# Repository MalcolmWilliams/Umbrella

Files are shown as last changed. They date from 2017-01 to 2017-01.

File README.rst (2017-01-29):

========
Umbrella
========

ESP8266 based smart umbrella for art show

Hardware
========

Prototyping is done on the `Adafruit HUZZAH ESP8266 Breakout <https://www.adafruit.com/product/2471>`_
The adafruit documentation is available here: https://learn.adafruit.com/adafruit-huzzah-esp8266-breakout/overview

Software
========

The program is written in Arduino with the help of platformio. 

Code written in microPython and Lua were also tested, but deemed to be less advantageous.

Uploading Code
**************

The board needs to be put in bootloader mode and then can be uploaded in a similar fashion to other arduino boards.
To put the board into bootloader mode:

1. Hold down reset button
2. Reset the board

To upload code, the script ``upload.sh`` can be run. Or the command ``platformio run -t upload`` can be run. 

PCB
===

The design was done in Altium 16. The project is located in ``./PCB/Smart_Umbrella_Altium/Smart_Umbrella/``.
Several of the board features include: LiPo battery charging, LED's, automatic bootloader mode, battery level sensing and IO breakouts.

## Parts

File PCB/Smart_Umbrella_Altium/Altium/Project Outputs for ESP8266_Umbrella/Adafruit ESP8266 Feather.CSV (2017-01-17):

Bill of Material for
On 1/17/2017 at 11:16:41 AM
Comment | Pattern | Quantity | Components
0.1µF | 0805 | 1 | C4
1µF | 0603 | 3 | C2, C3, C5
10µF | 0805 | 1 | C1
2.2nF | 0603 | 1 | C6
22µF | 0805 | 3 | C8, C9, C11
4.7µF | 0805 | 2 | C7, C10
6.8µH | L0603 | 1 | L1
CN3065 | DFN8G-0.5-3X3MM | 1 | U2
DHT-4235A | KMR2 | 1 | SW2
ESP-12 | ESP-12 | 1 | X1
ETA1036-50S2F | SOT-23-5 | 1 | 1
Green | LED-0603 | 1 | D8
Header 10 | HDR1X10 | 2 | P1, P2 | Header, 10-Pin
Header 6 | HDR1X6 | 1 | P3 | Header, 6-Pin
JSTPH | JST-2-SMD | 1 | J1
LED | LED_5MM | 3 | D5, D6, D7
MK-12C02 | SW7-SMD-L6.7X2.7X3.2MM | 1 | SW1
MMBT3904L | SOT23-3 | 2 | Q1, Q2 | Transistor NPNBJT configuration in SOT23 package. MMBT2222 is the common NPN we use. Double check BCE configuration again layout.
Orange | LED-0603 | 1 | D9
Red | LED-0603 | 1 | D4
Res3 | J1-0603 | 17 | R1, R2, R3, R4, R5, R6, R7, R8, R9, R10, R11, R12, R13, R14, R15, R16, R17 | Resistor
WS2812B5050 | WS2812B | 3 | D1, D2, D3
XC6204B332MR | SOT-23-5 | 1 | U1

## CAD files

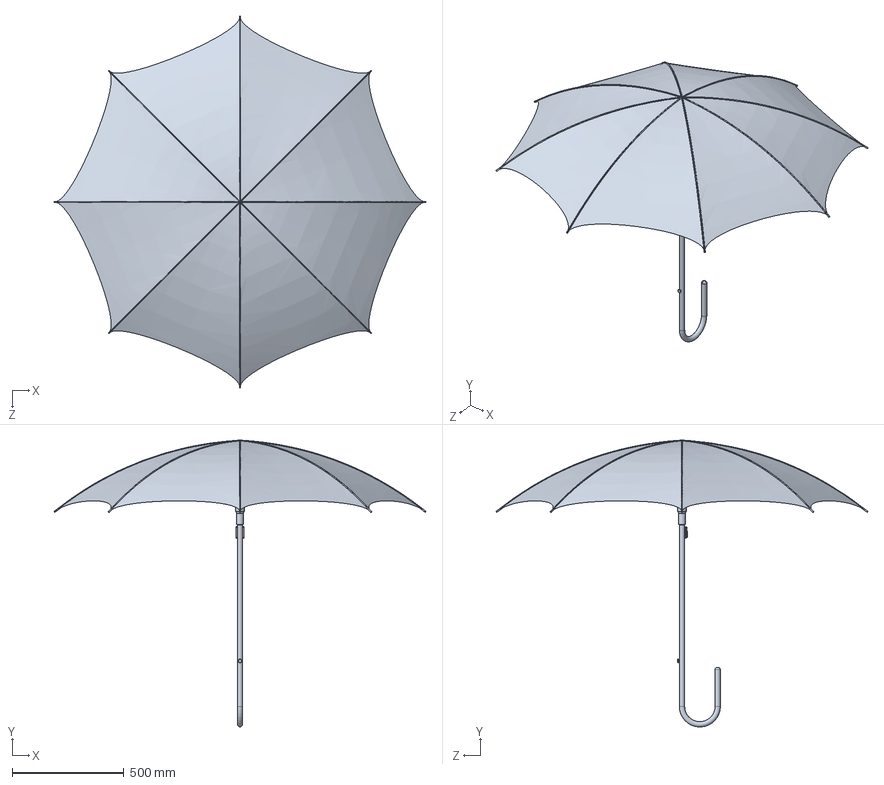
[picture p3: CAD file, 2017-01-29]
CAD/Smart_Umbrella_Assem.SLDASM
1665.4 x 1284.1 x 1665.4 mm
Umbrella
PCB
LiPo battery 500 mAh

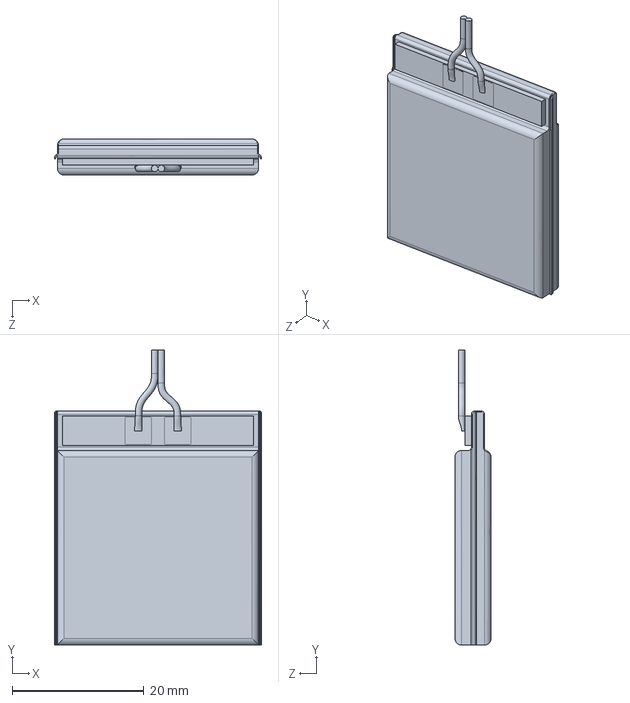
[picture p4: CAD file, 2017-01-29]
CAD/LiPo battery 500 mAh.SLDPRT
31.4 x 44.8 x 5.50 mm

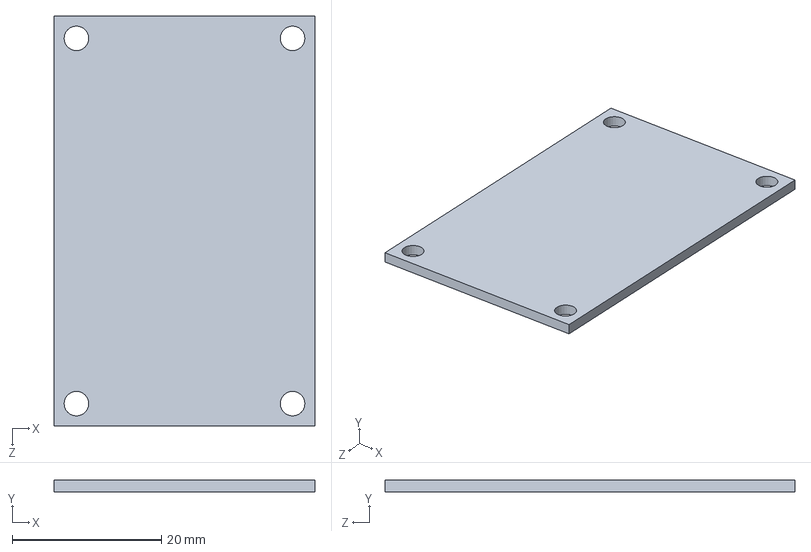
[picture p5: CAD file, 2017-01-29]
CAD/PCB.SLDPRT
35.0 x 1.60 x 55.0 mm

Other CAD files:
CAD/umbrella.SLDPRT

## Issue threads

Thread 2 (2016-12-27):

Power consumption

MalcolmWilliams, 2016-12-27:

MalcolmWilliams, 2017-01-17:
Average while scanning is 32.5 mA.
The white LED's will be 30mA on full brightness.
For full power operation with 500mAh battery: 500/(30*3+32.5) = 4 hours

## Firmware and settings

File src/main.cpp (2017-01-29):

/*
 * Only ESP plus small LED:
 * Average power consumption: 32.5mW
 * Max: 240mW
 */

#include "ESP8266WiFi.h"
#include "BrightnessMap.h"

unsigned long start_time; // = micros();
unsigned long end_time; // = micros();
int nets;
int LEDpin = 0;


void setBrightness(int val);
void printScanResult(int networksFound);


void printScanResult(int networksFound)
{
  int val = 0;
  //Serial.println();
  Serial.printf("%d network(s) found\n", networksFound);
  for (int i = 0; i < networksFound; i++)
  {
    //Serial.printf("%d: %s, Ch:%d (%ddBm) %s\n", i + 1, WiFi.SSID(i).c_str(), WiFi.channel(i), WiFi.RSSI(i), WiFi.encryptionType(i) == ENC_TYPE_NONE ? "open" : "");
    Serial.printf("%s, (%ddBm)\n", WiFi.SSID(i).c_str(), WiFi.RSSI(i));
  
  /*  
   *  -20 is the closest 
   *  -80 is the farthest 
   *  
   *  Need to come up with an algorythm that has the desired effect
   */
    //if(WiFi.SSID(i).c_str() == "ESP-AP") val += 100 - WiFi.RSSI(i);
    //if(WiFi.SSID(i).c_str() == "ESP-AP\n") val += 100 - WiFi.RSSI(i);
    if(WiFi.SSID(i) == "ESP-AP") val += 100 + WiFi.RSSI(i);
    //if(WiFi.SSID(i) == "ESP-AP\n") val += 100 - WiFi.RSSI(i);
  }

  setBrightness(val);
}

void setBrightness(int val)
{
  if (val > 100) val = 100;
  Serial.println(val);

  val = BrightnessMap[val]; //map the brightness to make the led brightness change appear linear (normally it will look logarithmic)
  analogWrite(LEDpin, (100-val)*PWMRANGE/100);
}



void setup()
{
  Serial.begin(115200);
  Serial.println();

  WiFi.mode(WIFI_STA);
  WiFi.disconnect();
  delay(100);

  pinMode(LEDpin, OUTPUT);
  analogWrite(LEDpin, 0);
}


void loop() {
  start_time = micros();
  int nets = WiFi.scanNetworks();
  printScanResult(nets);
  end_time = micros();
  Serial.print("Run Time: ");
  Serial.println((end_time - start_time)/1000000.0);
  
  }

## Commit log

2016-12-26 added pin-map image
2017-01-07 Initial Arduino Code
2017-01-15 start of altium work
    [Adafruit ESP8266 Feather.PcbDoc, Adafruit ESP8266 Feather.PrjPcb, Adafruit ESP8266 Feather.SchDoc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]
2017-01-17 first revision schematic complete
    [Adafruit ESP8266 Feather.PcbDoc, Adafruit ESP8266 Feather.SchDoc, Connector.PCBLIB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]
2017-01-17 schematic rev 1.1
    -change led data ports
    -aesthetic changes
    [Adafruit ESP8266 Feather.CSV, Adafruit ESP8266 Feather.PcbDoc, Adafruit ESP8266 Feather.SchDoc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]
2017-01-17 Start of folder cleanup
    [Smart_Umbrella.PcbDoc, Smart_Umbrella.PrjPcb, Smart_Umbrella.SchDoc]
2017-01-18 package of all pcb files
    [Smart_Umbrella.PcbDoc, Smart_Umbrella.PrjPcb]
2017-01-18 cleanup of altium work
    [Adafruit ESP8266 Feather.CSV, Adafruit ESP8266 Feather.PcbDoc, Adafruit ESP8266 Feather.PrjPcb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]
2017-01-19 pcb work
    [Adafruit ESP8266 Feather.CSV, Connector.PCBLIB, Connector.PrjPcb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]
2017-01-21 added python testing code
    [Part1.SLDPRT]
2017-01-29 Merge remote-tracking branch 'origin/master'
    # Conflicts:
    # PCB/Smart_Umbrella (1-18-2017 11-55-32
    AM)/Smart_Umbrella/__Previews/Smart_Umbrella.PcbDocPreview
    # PCB/Smart_Umbrella (1-18-2017 11-55-32
    AM)/Smart_Umbrella/__Previews/Smart_Umbrella.SchDocPreview
    [LiPo battery 500 mAh.SLDPRT, OMBRELLO_TERMINATO.SLDASM, PCB.SLDPRT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]
